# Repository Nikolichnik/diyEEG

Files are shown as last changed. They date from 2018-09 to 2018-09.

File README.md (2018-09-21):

# diyEEG
<h4>Attempt at building DIY EEG device.</h4>

<hr>

<p align="center">
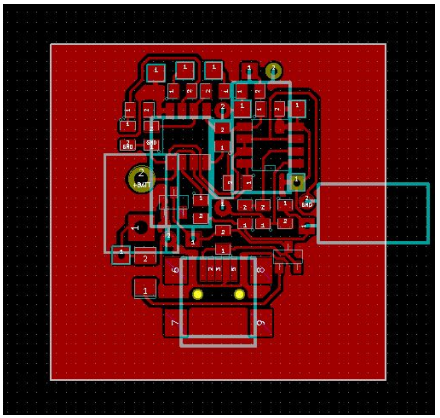
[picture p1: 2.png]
  
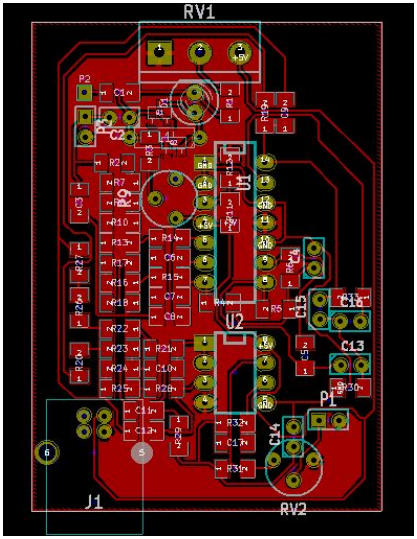
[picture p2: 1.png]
  
</p>

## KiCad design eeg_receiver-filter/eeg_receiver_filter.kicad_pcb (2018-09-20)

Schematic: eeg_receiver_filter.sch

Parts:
C1: 10pF
C2: 330uF
C3, C6, C7, C8, C9, C10, C11, C12: 1nF
C4, C13, C14, C15, C16: 1uF
C5, C17: 3.3nF
D1: RedHiBr
J1: USB
L1: 70nH/60nH*
P1: eeg_out
P2: CONN_1
P3: RX_out
Q1, Q2: BFR92
R1: 100k
R2, R7, R10, R13, R15, R19, R20, R21, R24, R25: 1.5M
R3, R9, R11, R12: 10k
R4, R5: 3k6
R6: 1M1
R8, R14, R23, R28: 180k
R16, R17, R18, R22, R26, R27: 30k
R29: 2k
R30: 22k
R31: 20k
R32: 200k
R33: 47k
RV1: 10k
RV2: 100k
U1: TLC274CD
U2: TLC272CD

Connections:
+5V: J1.1 (Vbus), R9.1, R11.1, RV1.3, U1.4 (V+), U2.8 (V+)
GND: C4.2, C14.2, R30.1, U1.1, U1.2 (-), U1.10 (+), U1.12 (+), U2.5 (+)
GNDPWR: J1.4 (GND), P1.2 (PM), P3.2 (PM), Q1.1 (E), Q2.1 (E), R12.2, RV1.1, RV2.1, U1.11 (V-), U2.4 (V-)
unnamed: C10.2, C11.2, R21.2, R29.1, U2.1, U2.2 (-)
unnamed: R21.1, R22.1
unnamed: R25.2, R28.1
unnamed: R24.2, R25.1
unnamed: R20.2, R23.2
unnamed: C10.1, C11.1, R23.1, R24.1
unnamed: C12.2, R28.2, U2.3 (+)
unnamed: R26.2, R27.2
unnamed: R22.2, R26.1
unnamed: C5.1, C13.1, R5.2, U1.8
unnamed: C16.2, R33.1, U1.13 (-)
unnamed: R16.2, R17.1
unnamed: R19.2, R20.1
unnamed: C13.2, C15.1, C16.1, R30.2
unnamed: C9.1, C15.2, R19.1, R33.2, U1.14
unnamed: C3.2, C8.1, R18.1
unnamed: C9.2, C12.1, R27.1
unnamed: P1.1, RV2.2
unnamed: C17.2, R32.2, U2.6 (-)
unnamed: C14.1, R29.2, R31.1, R32.1
unnamed: C17.1, R31.2, RV2.3, U2.7
unnamed: C1.2, D1.2 (K), R1.1
unnamed: R3.2, R9.2
unnamed: R1.2, RV1.2
unnamed: C2.2, C3.1, P3.1, R2.1
unnamed: R11.2, R12.1, U1.3 (+)
unnamed: C5.2, R6.2, U1.9 (-)
unnamed: C4.1, R4.2, R5.1, R6.1
unnamed: C6.2, C7.2, R4.1, R15.2, U1.6 (-), U1.7
unnamed: R15.1, R16.1
unnamed: C6.1, C7.1
unnamed: C8.2, R14.2, U1.5 (+)
unnamed: R17.2, R18.2
unnamed: C1.1, C2.1, L1.2, P2.1, Q1.3 (C), Q2.2 (B), R3.1
unnamed: R2.2, R7.1
unnamed: D1.1 (A), L1.1, Q1.2 (B), Q2.3 (C)
unnamed: R13.2, R14.1
unnamed: R10.2, R13.1
unnamed: R8.1, R10.1
unnamed: R7.2, R8.2

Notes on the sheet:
Fosc=1/(2*Pi*sqrt(L*C)) ____________________________ Unit1: C=10 pF + LED (red, HiBr 5mm) LED- (5V -> 0V) -> (2pF -> 3.6pF) Ct=(1.67pF -> 5.65pF) L=70 nF (9T, 3 mm (W), 9 mm (L)) Fosc=(369MHz -> 467MHz)
|- notch Fc=50.08Hz Hz G=1 -|
|- LPF Fc=44 Hz G=-1 -|
|- HPF Fc=4.9 Hz G=-1 -|
|- LPF Fc=43.8 Hz G=-10 -|
P1- filtered out P2- RX antenna P3- RX out_test
Unit2: C=10 pF + LED (red, HiBr 5mm) LED- (5V -> 0V) -> (2pF -> 3.6pF) Ct=(1.67pF -> 5.65pF) L=60 nF (8T, 3 mm (W), 8 mm (L)) Fosc=(399MHz -> 502MHz)
Gt=-10
|- final output curve (?) -|

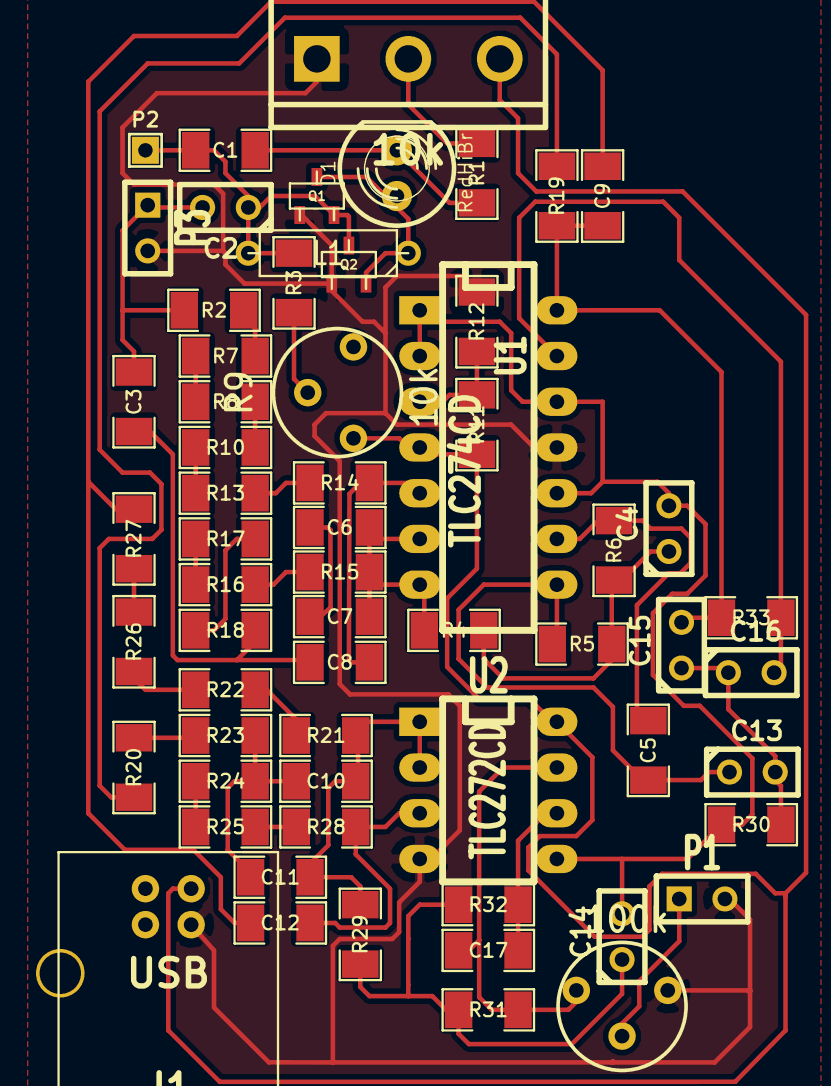
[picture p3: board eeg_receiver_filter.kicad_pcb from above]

Board: 2 copper layers, 62 parts (0 on the bottom side), 43 nets.

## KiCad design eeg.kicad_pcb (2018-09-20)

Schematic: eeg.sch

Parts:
C1, C2: 0.1nF
C3, C7, C10: 1nF
C4: 1uF
C5: 3.3nF
C6: 330uF
C8: 1.2pF/1.5pF*
C9: 5pF
C11: 100uF
D1: 4.7V
D2: 1N4007
J1: USB
L1: 0.1uH/0.1uH*
P1, P2, P3, P4, P5, P6, P7, P8: CONN_1
Q1, Q2: BFR92
R1, R2: 5k6
R3: 150R
R4: 2k2
R5, R7: 470k
R6: 8k2
R8: 100k
R9: 330R
R10: 560R
R11, R12: 10k
SW1: reed_switch
SW2: slide
U1: AD623
U2: TLC272CD

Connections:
+BATT: C8.1, C10.1, L1.2, R8.2, R11.1, SW2.2, U1.7 (V+), U2.8 (V+)
GND: C1.2, C2.1, C4.2, U1.5 (Ref), U2.3 (+), U2.6 (-), U2.7
GNDPWR: C7.2, C10.2, C11.2, D1.1, J1.4 (GND), P4.1, P7.1, P8.1, R9.1, R12.2, U1.4 (V_), U2.4 (V-)
unnamed: C9.2, Q1.1 (E), R9.2
unnamed: C6.2, C7.1, Q1.2 (B), R8.1
unnamed: R11.2, R12.1, U2.5 (+)
unnamed: D2.2 (K), P6.1, SW2.1
unnamed: D2.1 (A), Q2.1 (E)
unnamed: C5.1, R5.2, SW1.1, U2.1
unnamed: P3.1, R7.1, SW1.2
unnamed: C8.2, C9.1, L1.1, P5.1, Q1.3 (C)
unnamed: J1.1 (Vbus), Q2.3 (C), R10.1
unnamed: C11.1, D1.2, Q2.2 (B), R10.2
unnamed: R4.1, U1.6 (OUT)
unnamed: C4.1, R4.2, R5.1, R6.1
unnamed: C5.2, R6.2, U2.2 (-)
unnamed: P2.1, R2.1
unnamed: C2.2, C3.2, R2.2, U1.2 (-)
unnamed: C1.1, C3.1, R1.2, U1.3 (+)
unnamed: P1.1, R1.1
unnamed: R3.1, U1.8 (Rg)
unnamed: R3.2, U1.1 (Rg)
unnamed: C6.1, R7.2

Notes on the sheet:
Fosc=1/(2*Pi*sqrt(L*C)) ____________________________ Unit1: C=1.5 pF L=0.1 uF Fosc= 410.936296 MHz Unit2: C=1.2 pF L=0.1 uF Fosc=459.440746 MHz -------------------------------- Unit1: C=47 pF L=3.124 nF (2T, 2 mm (W), 4 mm (L)) Fosc= 409.494 MHz Unit2: C=22 pF L=5.430 nF (2T, 2 mm (W), 2 mm (L)) Fo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
AD623: ---------------------- Rg=100k/(G-1) G=100k/Rg+1 Rg=150R G=667 INA122 ---------------------- Rg=200k/(G-5) G=200k/Rg+5 _____________________________________ Gt=-142738 Vin=10 uV->30 uV Vout=1.42 V->4.28 V
| LPF Fc=44.6 Hz G=-214(46.56dB) |
|RFI reject Fc=25836 Hz|
P1- electrode1 in P2- electrode2 in P3- audio inject signal P4- audio inject ground P5- antenna P6- batt+ P7- batt- P8- ground electrode in
| LPF Fc=44.6 Hz (?) G=-214 (46.56dB) |

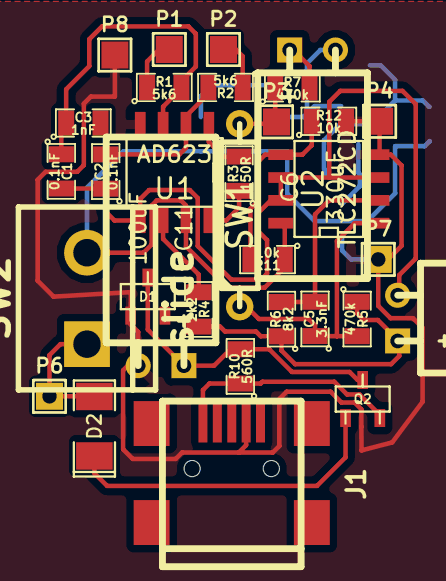
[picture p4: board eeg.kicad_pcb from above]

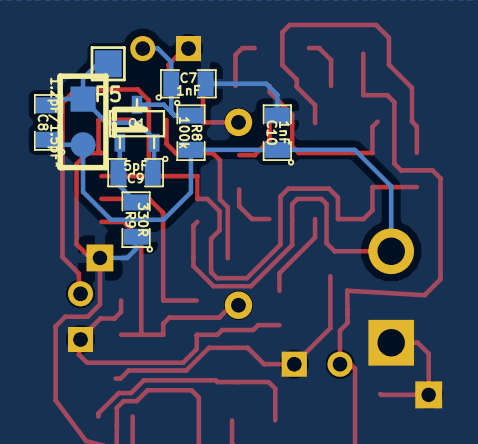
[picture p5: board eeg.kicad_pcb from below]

Board: 2 copper layers, 41 parts (9 on the bottom side), 23 nets.
